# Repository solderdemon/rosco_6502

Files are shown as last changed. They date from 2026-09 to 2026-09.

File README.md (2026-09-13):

# Really Old-School Computer - 6502

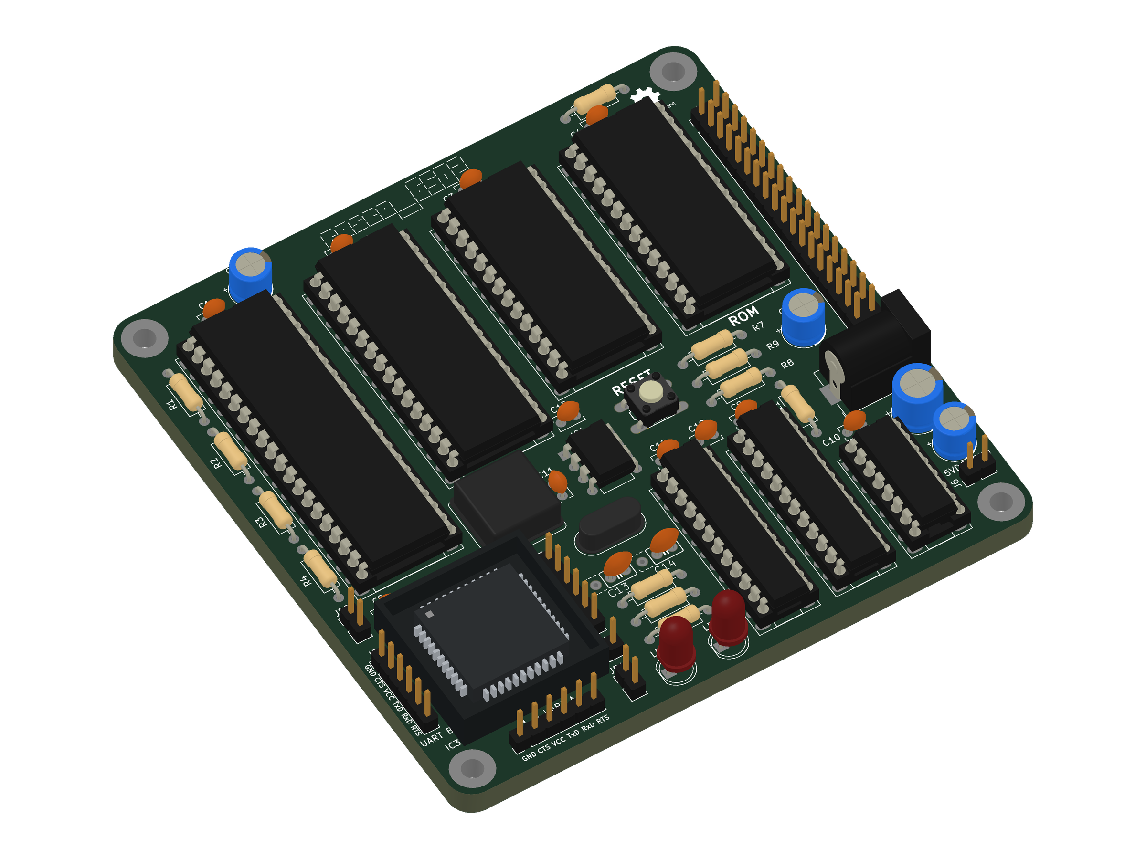
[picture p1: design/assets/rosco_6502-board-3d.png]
rosco_6502 r4 populated PCB in an orthographic 3D view


## A 65C02 Single-Board Computer

This repository holds design files, firmware and software for the Really Old-School Computer
(6502) single-board computer, AKA the rosco_6502. This is a fully-featured, programmable,
extensible and capable 8-bit retro computer that is completely open source.

The rosco_6502 is the "little brother" of the popular [rosco_m68k](https://github.com/rosco-m68k)
m68k computer. It is made by the same people, and shares the ethos of being powerful, extensible
and above all, fun.

This project contains all the design files and source code for the project.

* All Software released under the MIT licence. See LICENSE for details.
* All Hardware released under the CERN Open Hardware licence. See LICENCE.hardware.txt.
* All Documentation released under Creative Commons Attribution. See <https://creativecommons.org/licenses/by/2.0/uk/>

## Documentation

Start with the [documentation index](docs/README.md).

* [Getting started and terminal setup](docs/getting-started.md)
* [Hardware and memory map](docs/hardware.md)
* [Building and programming ROM](docs/rom-firmware.md)
* [Building and programming PLDs](docs/pld-firmware.md)
* [Developing and loading programs](docs/software.md)
* [Troubleshooting](docs/troubleshooting.md)
* [Revision 4 notes](docs/revision-4.md)

## Specifications

### Hardware

The hardware specifications for the rosco_6502 are:

* WDC 65C02 at up-to 14MHz (In theory, 10MHz testing target currently).
* SCN68681C1A44 provides two UARTs, timers and SD Card / SPI / GPIO; the console runs at 38400 bit/s
* 528KB RAM
  * 16KB low RAM ($0000 - $3FFF)
  * 16 x 32KB RAM banks ($4000 - $BFFF)
* 8KB IO space ($C000 - $DFFF)
* 8KB or 32KB (banked) ROM $E000 - $FFFF
* High-speed decode and glue logic handled by Atmel F22V10C PLDs.
* Comprehensive expansion and IO connectors allow the system to be easily expanded!

You can see the electrical designs in [kicad](design/kicad). Programmable logic lives in [pld](code/pld).

### Software

The current firmware uses the cc65 toolchain (`ca65`, `ld65` and `da65`).
It includes hardware initialization, WozMon, SD card access, read-only FAT32
support and boot code that looks for `/ROSC0DE_6502.BIN` on the SD card.
The firmware and filesystem utilities are still under development.

See the [firmware README](code/firmware/README.md) for build
instructions.

### Related tools

* [rosco CLI](https://github.com/solderdemon/rosco-cli): a cross-platform `rosco` command
  that creates, builds and uploads rosco_6502 (and rosco_m68k) programs over UART, or
  runs them in the emulator.
* [rosco-emulator](https://github.com/solderdemon/rosco-emulator): a slimmed-down MAME
  build that emulates the rosco_6502 r4, so programs and firmware can be tested without
  the board.

See [Developing and loading programs](docs/software.md#rosco-cli-and-emulator) for usage.

## Repository layout

* [design/kicad](design/kicad): board schematics and PCB layouts.
* [code/pld](code/pld): programmable logic sources.
* [code/firmware](code/firmware): ca65 firmware and ROM linker configurations.
* [code/software](code/software): example programs, tests and filesystem utilities.
* [docs](docs): additional project documentation.

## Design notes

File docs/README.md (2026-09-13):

# rosco_6502 Documentation

rosco_6502 is an open single-board computer built around the WDC 65C02, with banked memory, two UARTs and SD access over SPI. This guide covers the r4 board and the current ca65 firmware in this repository.

## Where to start

| Task | Guide |
| --- | --- |
| Power up the board and connect a terminal | [Getting started](getting-started.md) |
| Check power connections, ROM options and memory layout | [Hardware](hardware.md) |
| Build and program the EEPROM | [ROM firmware](rom-firmware.md) |
| Build JEDEC files and program IC2 and IC5 | [PLD firmware](pld-firmware.md) |
| Build a program and load it over UART or from SD | [Software development](software.md) |
| Build and run a program with the rosco CLI, with or without the board | [rosco CLI and emulator](software.md#rosco-cli-and-emulator) |
| Diagnose a failure | [Troubleshooting](troubleshooting.md) |
| Read the manufacturer's r4 notices | [Revision 4 notes](revision-4.md) |

For a new board, follow this sequence: inspect assembly and power connections → program both PLDs → program ROM → start with a terminal → load a RAM program.

## Repository layout

| Directory | Contents |
| --- | --- |
| [design/kicad](../design/kicad) | Schematic, PCB, symbol and footprint libraries, component CSV |
| [design/CAMOutputs](../design/CAMOutputs) | Gerber and drill files |
| [code/pld](../code/pld) | Logic equations, JEDEC files and programming scripts |
| [code/firmware](../code/firmware) | Main ca65 firmware |
| [code/software](../code/software) | Examples and filesystem utilities |

## Status and sources

The firmware is under development. FAT32 support is read-only; an API symbol does not necessarily identify an implemented function. Known limitations are documented in the ROM and troubleshooting guides.

Commands follow the Makefiles and scripts in this repository. Run `sh` blocks in Bash. On Windows, use an environment providing Bash, GNU Make and the required tools on PATH. Validate builds and physical programming in your own environment.

The former `r4 Information.docx` and `r4 Information.pdf` are replaced by [Revision 4 notes](revision-4.md), with technical details also included in the relevant guides. The schematic PDF in `design/kicad` remains a drawing.

## Licences

- Software: MIT, see [LICENSE](../LICENSE).
- Hardware: CERN Open Hardware Licence, see [LICENCE.hardware.txt](../LICENCE.hardware.txt).
- Documentation: [Creative Commons Attribution 2.0 UK](https://creativecommons.org/licenses/by/2.0/uk/), as stated in the project README.
- Original project authors: Ross Bamford and contributors. The r4 notice was issued by The Really Old-School Company Limited.

[Back to the project README](../README.md)

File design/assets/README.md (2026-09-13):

# Board preview assets

The main README uses `rosco_6502-board-3d.png`, an orthographic view rendered with OpenGL rasterization. It uses smooth surface normals, linear-light shading and soft rasterized highlights, with no ray tracing or shadow passes. The earlier bare-board top view is retained as `rosco_6502-board.png`.

## 3D models

The PCB references the KiCad 10 standard STEP library through `KICAD10_3DMODEL_DIR`. Install that library to resolve the models. DIP devices include socket models and IC bodies raised 3.5 mm above their normal mounting position. The 100 nF capacitors use compact 3.8 mm ceramic disc models with 2.5 mm lead pitch. C13/C14 retain their 5 mm ceramic disc models; S1 uses the Omron B3F-100x model.

The local [PLCC-44 model](../kicad/3dmodels/PLCC-44_socket_populated.wrl) illustrates the populated UART socket. Its geometry is approximate and is not a manufacturer model of the SCN68681C1A44 or a mechanical clearance specification. Its matching [box definitions](../kicad/3dmodels/PLCC-44_socket_populated.json) replace the converted PLCC geometry in the preview renderer to preserve its colours. The converted and local versions must not be drawn together, because overlapping surfaces cause artifacts. Local model coordinates are in millimetres in the JSON and converted to KiCad VRML units in the WRL.

The render preserves the board thickness and component placements in the PCB file. The preview uses charcoal sleeves for the stock blue electrolytic models. These are presentation colours; exact purchased part numbers were not specified. Generic models do not reproduce device markings or guarantee the dimensions and colours of the purchased components.

## Reproduce the image

Use KiCad 10 with its standard 3D library, Python, `numpy`, `trimesh`, `moderngl` and `Pillow`, and an OpenGL 3.3 capable graphics driver. Run from the repository root, with `kicad-cli` on PATH:

```sh
kicad-cli pcb export glb --output rosco-populated.glb --force --include-pads --include-silkscreen --include-soldermask design/kicad/rosco_6502.kicad_pcb
python design/assets/render_board.py rosco-populated.glb design/assets/rosco_6502-board-3d.png
```

The GLB is an intermediate file and does not need to be committed. The renderer adds the local UART visualization at the current IC3 position; update that placement in the script if IC3 is moved. It uses an orthographic camera and renders at twice the output resolution before downsampling to 1800 × 1400 pixels.

The local illustrative PLCC model is covered by the project's [hardware licence](../../LICENCE.hardware.txt). Standard KiCad models retain their upstream licences and are referenced rather than copied into this repository.

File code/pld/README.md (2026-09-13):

# rosco_6502 PLDs

[Building and programming PLDs](../../docs/pld-firmware.md) provides the full instructions for IC2 and IC5.

| Position | Source | JEDEC | Programming script |
| --- | --- | --- | --- |
| IC2 | [ic2_address_decoder.pld](address_decoder/ic2_address_decoder.pld) | [ic2_address_decoder.jed](address_decoder/ic2_address_decoder.jed) | [burn.sh](address_decoder/burn.sh) |
| IC5 | [ic5_glue_logic.pld](glue/ic5_glue_logic.pld) | [ic5_glue_logic.jed](glue/ic5_glue_logic.jed) | [burn.sh](glue/burn.sh) |

The scripts program existing JEDEC files into ATF22V10C(UES) devices. Run each script from its own directory. After changing equations, rebuild the JEDEC files as described in the guide before programming.

[Documentation index](../../docs/README.md)

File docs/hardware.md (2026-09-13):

# Hardware and memory map

[Documentation index](README.md)

## Main components

| Component | Purpose |
| --- | --- |
| WDC 65C02 | CPU |
| SCN68681C1A44 | Two UARTs, timer, GPIO for SPI and indicators |
| 16 KiB low RAM | Permanently mapped memory, stack and system structures |
| 16 × 32 KiB RAM | Banked memory; 528 KiB total including low RAM |
| AT28C64B or AT28C256 | 8 KiB ROM or four 8 KiB banks |
| IC2 | Address decoder PLD |
| IC5 | Glue logic PLD |

The original README specifies up to 14 MHz in theory, with 10 MHz as the testing target. This does not guarantee that every combination of components will operate at that frequency.

The current board uses an SCN68681C1A44 DUART, with the console configured for 38400 bit/s. Older design files and source comments may still refer to the previous XR68C681 device; check them against the populated board.

## CPU address space

| CPU addresses | Window size | Purpose |
| --- | --- | --- |
| `$0000–$3FFF` | 16 KiB | Low RAM; writes at the beginning also control banking |
| `$4000–$BFFF` | 32 KiB | Selected RAM bank, 0–15 |
| `$C000–$C00F` | 16 bytes | DUART registers |
| `$C010–$DFFF` | Remaining I/O | Reserved I/O space |
| `$E000–$FFFF` | 8 KiB | ROM; one of four banks with an AT28C256 |

`BANK_SET = $0000`: bits 0–3 select RAM and bits 4–5 select ROM. Preserve the ROM bits when changing the RAM bank. Do not switch banks while executing in the affected window without a deliberately arranged transition.

The headers reserve `$0001` as `BANK_RSVD`, but the IC2 equation decodes both `$0000/$0001`. Do not use either address as an ordinary variable. Reads return the contents of the underlying RAM.

## System RAM

| Range | Usage |
| --- | --- |
| `$0002–$000F` | Firmware zero page |
| `$0010–$001F` | Filesystem zero page according to the constants |
| `$0020–$002F` | Monitor zero page according to the constants |
| `$0030–$003F` | Avoid in portable examples: comments and constants disagree |
| `$0040–$00FF` | Application zero page in the example linker configurations |
| `$0100–$01FF` | CPU stack |
| `$0200–$023F` | Firmware variables and reserved space |
| `$0240–$029F` | RAM vector area |
| `$02A0–$02FF` | ROM switching helper code |
| `$0300–$03FF` | Input buffer |
| `$0400–$05FF` | Filesystem sector buffer |
| `$0600–$06FF` | Filename buffer |
| `$0700–$07FF` | Scratch buffer / bank copying |
| `$0800–$3FFF` | 14 KiB low RAM for applications |

The introductory table in `defines.inc` disagrees with the constants about zero page and the RAM vector boundaries. The vector boundaries above follow the linker configuration. The conservative application zero-page start follows the example configurations (`$0040`).

## Board design files

- [KiCad schematic](../design/kicad/rosco_6502.kicad_sch), [PDF schematic](../design/kicad/rosco_6502.pdf).
- [PCB](../design/kicad/rosco_6502.kicad_pcb), [KiCad project](../design/kicad/rosco_6502.kicad_pro).
- [Component CSV](../design/kicad/rosco_6502.csv), [manufacturing files](../design/CAMOutputs).
- [Firmware constants](../code/firmware/inc/defines.inc), [ROM linker configuration](../code/firmware/rosco_6502_32K.cfg).

Before manufacturing, check that the schematic, PCB and Gerber revisions match. The PLD source headers still say r1, whereas the hardware notice covers r4.

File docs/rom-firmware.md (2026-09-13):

# Building and programming ROM

[Documentation index](README.md)

The main firmware is in [code/firmware](../code/firmware). It initializes the DUART, timer and RAM vectors, checks memory banks and attempts to load a program from SD. If loading fails or the program returns with RTS, execution enters WozMon.

## Tools

You need `ca65`, `ld65` and `da65` from cc65, GNU Make, Bash, `cat` and `rm`. Programming also requires `minipro` and a programmer supporting the specific EEPROM. On Windows, run the commands in a Bash environment; USB programmer access must be configured separately.

Check tool availability in Bash:

```sh
command -v make bash ca65 ld65 da65 cat rm
command -v minipro
```

## Choose an image

| EEPROM | Image | Size | Programming target |
| --- | --- | --- | --- |
| AT28C64B | `boot8k.bin` | 8192 bytes | `make burn8` |
| AT28C256 | `boot32k.bin` | 32768 bytes | `make burn32` |

ROM appears at CPU address `$E000`, but the image is programmed from EEPROM offset 0. A RAM program intended for SD boot is not a ROM image.

## Build

From the repository root:

```sh
cd code/firmware
make clean
make all
wc -c boot8k.bin boot32k.bin
```

To build only one variant, run `make boot8k.bin` or `make boot32k.bin` after `make clean`.

Clean before rebuilding: the assembly rule references `S_INCLUDES`, but the Makefile does not define it. Editing an included `.s` or `.inc` file may therefore fail to trigger an object rebuild.

The 32 KiB image concatenates `boot32k.0.bin`, `boot32k.1.bin`, `boot32k.2.bin` and `boot32k.3.bin` in that order. Each bank is 8192 bytes. Program the combined `boot32k.bin` into an AT28C256.

Other outputs are `.lst` listings, `.sym` symbols, `.map` linker maps and `.dis` disassemblies. Existing files without the `.bin` extension do not replace the output of a clean build.

## Program the EEPROM

1. Disconnect board power, remove the EEPROM and check its markings.
2. Insert the EEPROM into the programmer using its placement guide and pin 1 orientation.
3. From the firmware directory, run only the target for the installed chip:

```sh
# AT28C64B, 8 KiB
make burn8
```

or:

```sh
# AT28C256, 32 KiB
make burn32
```

These Makefile targets execute the following commands respectively:

```sh
minipro -p AT28C64B -s -w boot8k.bin
minipro -p AT28C256 -s -w boot32k.bin
```

The commands are alternatives for different chips. Check the programmer's write and verification results before reinstalling the EEPROM. If your minipro version does not recognize the required chip, do not substitute another device profile.

4. Reinstall the EEPROM in the correct orientation with board power disconnected.
5. Follow [Getting started](getting-started.md). Startup code attempts to detect the ROM bank count. An incorrect result calls for checking the image and hardware bank selection.

## Source layout

| File | Responsibility |
| --- | --- |
| [bank0.s](../code/firmware/bank0.s) | Reset, initialization, checks and SD boot |
| [bank1.s](../code/firmware/bank1.s), [bank2.s](../code/firmware/bank2.s), [bank3.s](../code/firmware/bank3.s) | Other ROM banks |
| [common.s](../code/firmware/common.s), [vectors.s](../code/firmware/vectors.s) | Common code and CPU vectors |
| [romtable.s](../code/firmware/romtable.s), [ramtable.s](../code/firmware/ramtable.s) | Call tables and bank transitions |
| [duart_spi.s](../code/firmware/duart_spi.s), [sd_card.s](../code/firmware/sd_card.s) | SPI and SD |
| [fat32_readonly.s](../code/firmware/fat32_readonly.s) | FAT32 reading |
| [wozmon.s](../code/firmware/wozmon.s) | Monitor and Intel HEX loader |

The `rosco_6502_8K.cfg` and `rosco_6502_32K.cfg` linker configurations define the layout. CPU vectors start at `$FFFA`. Common regions must retain matching addresses across all banks.

## Limitations

The ROM table routes `FAT_READ`, `FAT_SEEK`, `FAT_WRITE` and `FAT_CLOSE` to a stub. Use implemented operations such as `FS_READBYTE` and `FS_READFILE` for reading. The current `CLRSCR`, `MOVEXY` and `SETCURSOR` RAM vectors jump to themselves; calling them directly can hang execution.

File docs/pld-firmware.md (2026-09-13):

# Building and programming PLDs

[Documentation index](README.md)

The PLDs implement hardware logic. Their JEDEC files are programmed separately from the EEPROM; building ROM does not update the PLDs.

## Device and file mapping

| Position | Function | Directory | Programming file |
| --- | --- | --- | --- |
| IC2 | Address decoder | [address_decoder](../code/pld/address_decoder) | `ic2_address_decoder.jed` |
| IC5 | Glue logic | [glue](../code/pld/glue) | `ic5_glue_logic.jed` |

Both `burn.sh` scripts use the `ATF22V10C(UES)` profile. The source files specify the `GAL22V10` architecture; this does not mean any GAL is a suitable replacement for the actual device. Check the chip markings and your board schematic.

## Files and tools

- `.pld`: source equations and pin assignments.
- `.jed`: JEDEC data for the programmer.
- `.pin`, `.chp`, `.fus`: pin, package and fuse-array reports.
- `burn.sh`: programs an existing JEDEC file without compiling it.

The checked-in JEDEC headers identify **GALasm 2.1**. Rebuilding requires GALasm. Programming requires Bash, minipro and a compatible programmer. See the [GALasm documentation](https://github.com/daveho/GALasm#readme) for syntax and options.

## Rebuild after changing the logic

From the repository root, build each PLD separately:

```sh
cd code/pld/address_decoder
galasm ic2_address_decoder.pld
```

```sh
cd code/pld/glue
galasm ic5_glue_logic.pld
```

The second block also starts from the repository root. The executable name depends on your installation: use `GALasm` instead of `galasm` if that is its name.

Compilation must finish without errors and generate the corresponding `.jed`. Review the pin reports and run `git diff -- code/pld` from the repository root to inspect changes. Do not program after a failed build: an older JEDEC file may still be present. This repository has no separate PLD Makefile.

If the equations have not changed, you can use the checked-in JEDEC files after confirming the board revision and device assignments.

## Program IC2

With board power disconnected, remove IC2 and insert it into the programmer according to its placement instructions. From the repository root:

```sh
cd code/pld/address_decoder
bash burn.sh
```

The script executes:

```sh
minipro -p 'ATF22V10C(UES)' -w ic2_address_decoder.jed
```

## Program IC5

Insert IC5 into the programmer separately. From the repository root:

```sh
cd code/pld/glue
bash burn.sh
```

The equivalent command is:

```sh
minipro -p 'ATF22V10C(UES)' -w ic5_glue_logic.jed
```

Quotes protect the parentheses in the device profile from Bash interpretation. The scripts use relative paths, so run each from its own directory.

After each operation, confirm that writing and verification completed successfully. Label the devices IC2 and IC5 to avoid mixing them up, then reinstall them in the correct orientation with board power disconnected.

## What the equations implement

IC2 selects low RAM, banked RAM, I/O, ROM, the DUART and the bank register. `BANKSEL` is active high; both `$0000` and `$0001` activate it.

IC5 generates `RD`, `WR`, `BANKCLK` and two ROM output-enable signals, and controls `RESET` and `RDY`. The source comment explains the two `BANKCLK` pulses during a write: an intermediate incorrect value is replaced by the correct value before banked RAM is used. This is an intentional timing tradeoff; changes require hardware measurements.

After installation, check ROM startup and the RAM banks. Successful JEDEC verification confirms device programming, but does not validate board timing. See [Troubleshooting](troubleshooting.md).

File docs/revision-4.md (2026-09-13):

# Revision 4 notes

[Documentation index](README.md)

This is a Markdown adaptation of **rosco_6502 Additional Information v1 (Jan 2024)** issued by The Really Old-School Company Limited. It replaces `r4 Information.docx` and `r4 Information.pdf`. The information applies to revision 4.

## JP1 and JP2

JP1 and JP2 are optional jumpers for powering the board through an FTDI module. Only one jumper may be closed at a time, and only when the board receives power from the corresponding module.

Do not close either jumper when external power is connected, and do not close both at once. Doing so may damage the board, FTDI modules, power supply and connected equipment.

The FTDI module and USB source must provide at least 400 mA for the main board alone. Insufficient power may cause incorrect operation and, in rare cases, permanent damage.

## Power connection

When not using FTDI power, supply 5 V DC through J6, the two-pin header at the bottom right of the board, or through J7, the barrel jack.

Higher voltage or incorrect polarity may permanently damage the board and peripherals. Follow the polarity markings on the board. J7 requires a centre-positive plug.

## ROM selection

The board supports an 8 KiB AT28C64B or a banked 32 KiB AT28C256. Program the standard firmware build matching the EEPROM capacity. The standard firmware detects and reports the ROM size at startup.

See the [ROM programming guide](rom-firmware.md) for commands.

## Manufacturer notices

The following preserves the substance of the manufacturer's January 2024 notices. It is not a new compliance assessment of an individually assembled board.

The manufacturer states that it has sought to make documentation accurate at the time of writing, subject to errors and omissions.

Compliance with local electromagnetic interference requirements may require a suitable grounded enclosure with application-specific shielding. The Really Old-School Company Limited neither specifies nor supplies such enclosures and recommends seeking expert guidance when selecting one.

The manufacturer does not authorize its products for safety-critical or life-support applications where a product failure could cause system failure or significantly affect system safety or effectiveness. Examples include human life support, nuclear safety and control, air-traffic control and vehicular control. Such use is not authorized under any circumstances.

According to the manufacturer, the PCBs and components it supplies comply with RoHS. Compliance of a completed kit also depends on the solder selected during assembly.

Dispose of waste in accordance with the applicable Waste Electrical and Electronic Equipment (WEEE) recycling requirements in your jurisdiction.

## Editorial notes

The original jumper warning referred to `rosco_m68k`; this adaptation uses “the board” to match the document's subject. Repeated section numbering has been replaced with headings. Power requirements and manufacturer notices have been preserved in substance.

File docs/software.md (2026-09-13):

# Developing and loading programs

[Documentation index](README.md)

RAM programs are built separately from ROM. The current ca65 examples link for execution at `$0800`, use the main firmware headers and can produce binary and Intel HEX files.

## Examples

| Directory | Purpose |
| --- | --- |
| [msg_test_ca65](../code/software/msg_test_ca65) | Simple message input and output |
| [fs_test_ca65](../code/software/fs_test_ca65) | Filesystem test |
| [fs_menushell](../code/software/fs_menushell) | Experimental filesystem utility |
| [msg_test](../code/software/msg_test), [sd_test](../code/software/sd_test), [fat_test](../code/software/fat_test) | Older VASM examples |

`fs_menushell` is not yet a complete command shell: its active path accepts input, passes it to `showdir` and exits.

## rosco CLI and emulator

Two companion projects cover the develop–upload–run loop outside this repository:

- [rosco CLI](https://github.com/solderdemon/rosco-cli) provides the `rosco` command for Linux and Windows. It creates a rosco_6502 project (a Makefile, sources and an ld65 configuration linked at `$0800`), builds it with cc65 either in Docker or on the host, uploads the binary as Intel HEX through the monitor, and shows the program's output.
- [rosco-emulator](https://github.com/solderdemon/rosco-emulator) is a MAME-based emulator with a `rosco_6502` machine: W65C02S, 16KB low RAM, 16 × 32KB RAM banks, banked ROM, XR68C681 DUART and SPI SD card. It can boot your own ROM image as well as run a program on the stock firmware.

A typical session with the CLI:

```sh
cargo install --path .          # in a rosco-cli checkout
rosco init hello --board rosco_6502 --language asm --target emulator
cd hello
rosco build
rosco run                       # in the emulator; use --hardware for the board
```

To run an existing binary directly in the emulator:

```sh
./rosco rosco_6502 -quik msg_test.bin
```

See each project's README for installation, the Docker images and all options. Validate results on the physical board as well, since the emulator does not reproduce every hardware timing detail.

## Build the test program

Use the same tools as for [ROM](rom-firmware.md), plus `srec_cat` to generate Intel HEX.

```sh
cd code/software/msg_test_ca65
make clean
make all
```

The outputs are `msg_test.bin` and `msg_test.hex`. If you only need the binary, run `make msg_test.bin`; this does not invoke `srec_cat`. Perform a clean build, especially after changing included files.

## Load through WozMon

1. Start the board without an SD boot file to enter the monitor.
2. Type `L` and press Enter.
3. Send `msg_test.hex` as text through the terminal. The loader expects Intel HEX, not XMODEM or a raw binary.
4. Wait for completion with no checksum errors.
5. Type `0800R` and press Enter.

If characters are lost during transfer, add a delay between lines in the terminal and retry. Do not run the program after a checksum error.

Useful monitor commands:

| Command | Action |
| --- | --- |
| `0800` | Inspect a byte |
| `0800.080F` | Inspect a range |
| `0800: A9 41 60` | Write bytes to RAM |
| `0800R` | Call the program at that address |
| `L` | Load Intel HEX |

## Boot from SD

The current FAT32 code searches the MBR for a partition of type `$0B` or `$0C` and checks for 512-byte sectors. Use an SDHC card with MBR partitioning and FAT32 for this boot path. exFAT, GPT and media without a partition table do not match this initialization path.

1. Back up any needed data before repartitioning or formatting the card.
2. Copy the RAM binary to the FAT32 root directory as **ROSC0DE_6502.BIN**. The character in `ROSC0DE` is the digit **0**.
3. For a test, copy and rename the built `msg_test.bin`. The boot filename exceeds 8.3 format, so preserve its full long filename.
4. Insert the card and restart the board.

The loader reads the file starting at `$0800` and executes `JSR $0800` after a successful read. The binary must not contain a load-address header. On reaching `$C000`, the reader continues at `$4000` in the next RAM bank. This does not give the application a linear address space beyond 64 KiB.

## Write your own program

Include `defines.inc` from the current firmware and use an example linker configuration. Start application zero page at `$0040`; leave system buffers and RAM vectors available to the firmware.

A minimal character output program, following normal ROM initialization:

```asm
.include "defines.inc"

.segment "CODE"
.global _start
_start:
    lda #'A'
    jsr PRINTCHAR
    rts
```

`PRINTCHAR` takes the character in A. `INPUTCHAR` waits for input and returns the character in A. For `FS_OPEN`, pass the string address with the low byte in A and the high byte in X. Check headers and implementations for other function contracts; do not assume registers are preserved.

Returning with RTS works if the program has maintained a valid stack. When using banking and the filesystem, follow the [memory map](hardware.md) and account for the [API limitations](rom-firmware.md).

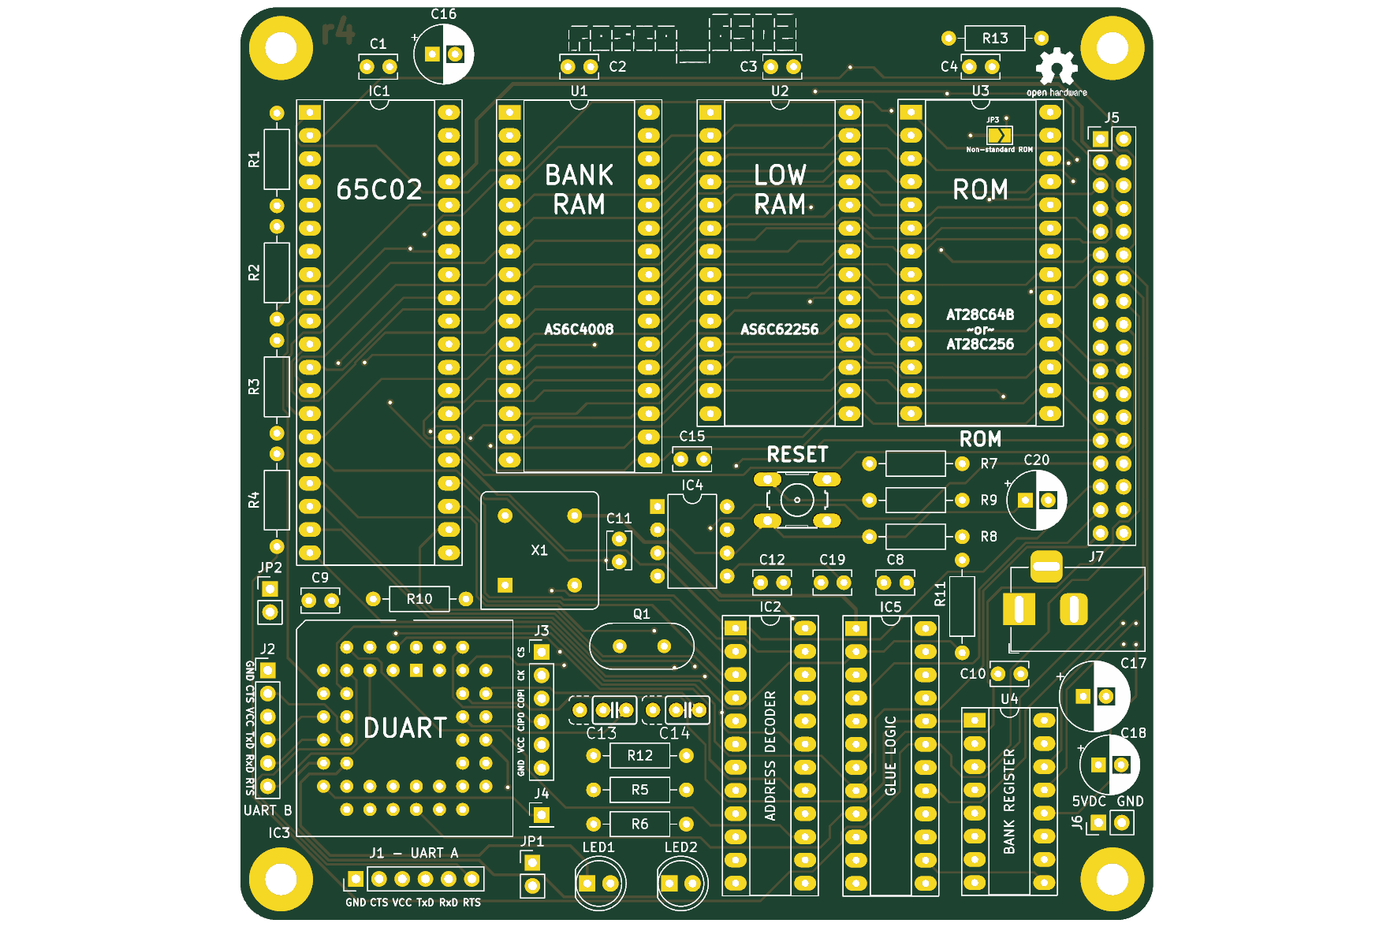
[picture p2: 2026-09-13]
design/assets/rosco_6502-board.png

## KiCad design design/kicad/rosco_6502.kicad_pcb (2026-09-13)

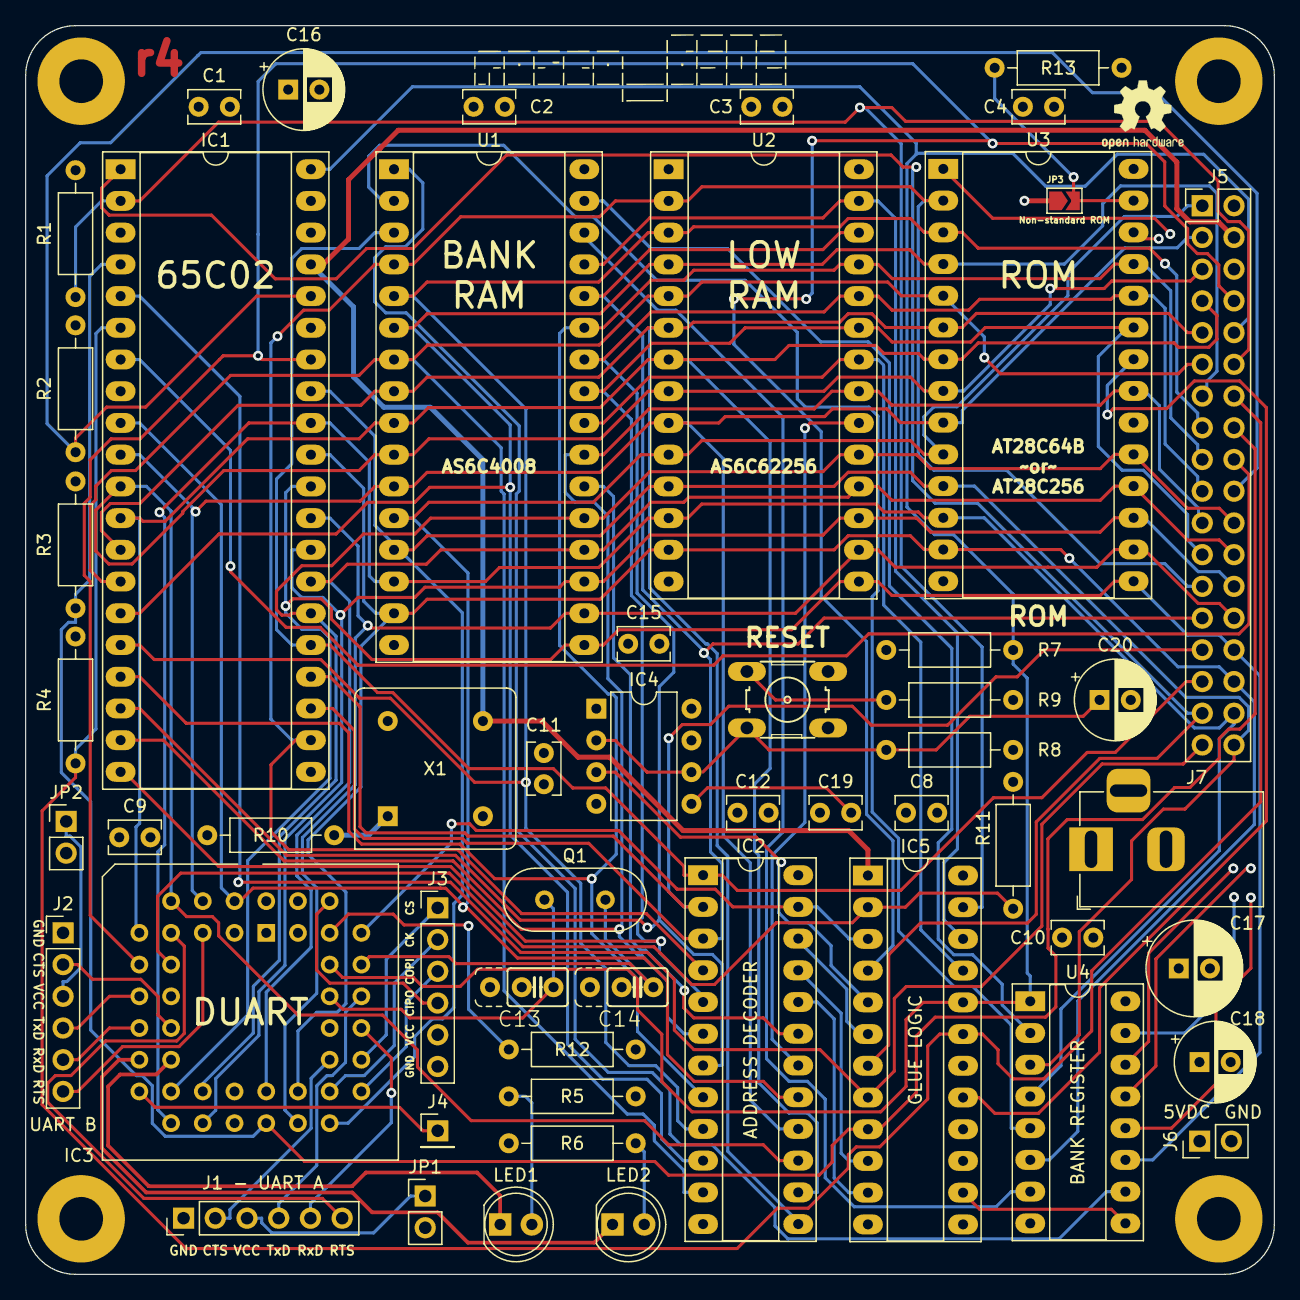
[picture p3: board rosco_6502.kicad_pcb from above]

Board: 4 copper layers, 100.0 x 100.0 mm, 60 parts (0 on the bottom side), 81 nets.

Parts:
C1, C2, C3, C4, C8, C9, C10, C11, C12, C15, C19: 100nF; C_Rect_L4.0mm_W2.5mm_P2.50mm
C13, C14: 7pF; C2.5_or_3.5-3
C16, C18: 100uF; CP_Radial_D6.3mm_P2.50mm
C17: 470uF; CP_Radial_D7.5mm_P2.50mm
C20: 10uF; CP_Radial_D6.3mm_P2.50mm
H1, H2, H3, H4: MountingHole_Pad; MountingHole_3.5mm_Pad
IC1: W65C02SxP; DIP-40_W15.24mm_Socket_LongPads
IC2, IC5: ATF22V10C-7PX; DIP-24_W7.62mm_Socket_LongPads
IC3: XR68C681CJTR-F; PLCC-44_THT-Socket
IC4: NE555P; DIP-8_W7.62mm
J1: UART_A; PinHeader_1x06_P2.54mm_Vertical
J2: UART_B; PinHeader_1x06_P2.54mm_Vertical
J3: Conn_01x06; PinHeader_1x06_P2.54mm_Vertical
J4: Conn_01x01_Male; PinHeader_1x01_P2.54mm_Vertical
J5: Conn_02x18_Odd_Even; PinHeader_2x18_P2.54mm_Vertical
J6: Conn_01x02_Pin; PinHeader_1x02_P2.54mm_Vertical
J7: Jack-DC; BarrelJack_Horizontal
JP1, JP2: Jumper; PinHeader_1x02_P2.54mm_Vertical
JP3: SolderJumper_2_Open; SolderJumper-2_P1.3mm_Open_TrianglePad1.0x1.5mm
LED1: GREEN; LED_D5.0mm
LED2: RED; LED_D5.0mm
Q1: 3.6864MHz; Crystal_HC49-4H_Vertical
R1, R2, R3, R4, R7, R10, R11, R12, R13: 3K3; R_Axial_DIN0207_L6.3mm_D2.5mm_P10.16mm_Horizontal
R5, R6, R9: 330R; R_Axial_DIN0207_L6.3mm_D2.5mm_P10.16mm_Horizontal
R8: 2K2; R_Axial_DIN0207_L6.3mm_D2.5mm_P10.16mm_Horizontal
S1: 10-XX; B3F-10XX
U1: AS6C4008-55PCN; DIP-32_W15.24mm_Socket_LongPads
U2: AS6C62256-55PCN; DIP-28_W15.24mm_Socket_LongPads
U3: AT28C256-15PU; DIP-28_W15.24mm_Socket_LongPads
U4: 74HCT174; DIP-16_W7.62mm_Socket_LongPads
X1: 14MHz; Oscillator_DIP-8
ohw: OSHW-Logo2_7.3x6mm_SilkScreen
rosco6502: rosco_6502

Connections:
A0: IC1.9 (A0), IC2.17 (I04), IC3.2 (A1), J5.1, U1.12 (A0), U2.10 (A0), U3.10 (A0)
A1: IC1.10 (A1), IC2.16 (IO3), IC3.4 (A2), J5.3, U1.11 (A1), U2.9 (A1), U3.9 (A1)
A2: IC1.11 (A2), IC2.15 (IO2), IC3.6 (A3), J5.5, U1.10 (A2), U2.8 (A2), U3.8 (A2)
A3: IC1.12 (A3), IC2.14 (IO1), IC3.7 (A4), J5.7, U1.9 (A3), U2.7 (A3), U3.7 (A3)
A4: IC1.13 (A4), IC2.13 (I13), J5.9, U1.8 (A4), U2.6 (A4), U3.6 (A4)
A5: IC1.14 (A5), IC2.11 (I11), J5.11, U1.7 (A5), U2.5 (A5), U3.5 (A5)
A6: IC1.15 (A6), IC2.10 (I10), J5.13, U1.6 (A6), U2.4 (A6), U3.4 (A6)
A7: IC1.16 (A7), IC2.9 (I9), J5.15, U1.5 (A7), U2.3 (A7), U3.3 (A7)
A8: IC1.17 (A8), IC2.8 (I8), J5.17, U1.27 (A8), U2.25 (A8), U3.25 (A8)
A9: IC1.18 (A9), IC2.7 (I7), J5.19, U1.26 (A9), U2.24 (A9), U3.24 (A9)
A10: IC1.19 (A10), IC2.6 (I6), J5.21, U1.23 (A10), U2.21 (A10), U3.21 (A10)
A11: IC1.20 (A11), IC2.5 (I5), J5.23, U1.25 (A11), U2.23 (A11), U3.23 (A11)
A12: IC1.22 (A12), IC2.4 (I4/PD), J5.25, U1.4 (A12), U2.2 (A12), U3.2 (A12)
A13: IC1.23 (A13), IC2.3 (I3), J5.27, U1.28 (A13), U2.26 (A13)
A14: IC1.24 (A14), IC2.2 (I2), J5.29
A15: IC1.25 (A15), IC2.1 (I1/CLK), J5.31, U1.3 (A14)
BANK0: U1.31 (A15), U4.2 (Q0)
BANK1: U1.2 (A16), U4.5 (Q1)
BANK2: U1.30 (A17), U4.7 (Q2)
BANK3: U1.1 (A18), U4.10 (Q3)
BANK4: U3.26 (A13), U4.15 (Q5)
BANK5: U3.1 (A14), U4.12 (Q4)
BANKCLK: IC5.14 (IO1), U4.9 (Cp)
BANKSEL: IC2.22 (IO9), IC5.6 (I6)
BE: IC1.36 (BE), J5.20, R2.2
CLK: IC1.37 (ϕ0), IC5.1 (I1/CLK), J5.4, X1.5 (OUT)
CTSA: IC3.8 (IP0), J1.6
CTSB: IC3.5 (IP1), J2.6
D0: IC1.33 (D0), IC3.28 (D0), J5.36, U1.13 (DQ0), U2.11 (DQ0), U3.11 (DQ0), U4.3 (D0)
D1: IC1.32 (D1), IC3.18 (D1), J5.34, U1.14 (DQ1), U2.12 (DQ1), U3.12 (DQ1), U4.4 (D1)
D2: IC1.31 (D2), IC3.27 (D2), J5.32, U1.15 (DQ2), U2.13 (DQ2), U3.13 (DQ2), U4.6 (D2)
D3: IC1.30 (D3), IC3.19 (D3), J5.30, U1.17 (DQ3), U2.15 (DQ3), U3.15 (DQ3), U4.11 (D3)
D4: IC1.29 (D4), IC3.26 (D4), J5.28, U1.18 (DQ4), U2.16 (DQ4), U3.16 (DQ4), U4.14 (D5)
D5: IC1.28 (D5), IC3.20 (D5), J5.26, U1.19 (DQ5), U2.17 (DQ5), U3.17 (DQ5), U4.13 (D4)
D6: IC1.27 (D6), IC3.25 (D6), J5.24, U1.20 (DQ6), U2.18 (DQ6), U3.18 (DQ6)
D7: IC1.26 (D7), IC3.21 (D7), J5.22, U1.21 (DQ7), U2.19 (DQ7), U3.19 (DQ7)
GND: C1.1, C2.1, C3.1, C4.1, C8.1, C9.1, C10.1, C11.1, C12.1, C13.1, C14.1, C15.1, C16.2, C17.2, C18.2, C20.2, H1.1, H2.1, H3.1, H4.1, IC1.21 (VSS), IC2.12 (GND), IC3.3 (IP3), IC3.22 (GND), IC4.1 (GND), IC5.12 (GND), J1.1, J2.1, J3.6, J5.6, J6.2, J7.2, JP3.1 (A), R9.2, U1.16 (VSS), U2.1 (A14), U2.14 (VSS), U3.14 (VSS), U3.20 (CE#), U4.8 (GND), X1.4 (GND)
HWRST: IC4.3 (Q), IC5.5 (I5)
IRQ: IC1.4 (~IRQ), IC3.24 (INTR), IC5.9 (I9), J5.16, R3.2
NMI: IC1.6 (~NMI), IC5.19 (IO6), J5.14, R4.2
unnamed: IC3.41 (*IACK), R12.2
unnamed: IC3.15 (OP3), LED2.1 (K)
unnamed: IC3.16 (OP5), LED1.1 (K)
unnamed: C13.2, IC3.36 (X1/CLK), Q1.1
unnamed: C14.2, IC3.37 (X2), Q1.2
unnamed: C19.2, IC4.5 (CV)
unnamed: C20.1, IC4.2 (TR), IC4.6 (THR), R8.1, S1.3
unnamed: JP3.2 (B), R13.1, U3.27 (WE#)
unnamed: LED1.2 (A), R5.1
unnamed: LED2.2 (A), R6.2
unnamed: R9.1, S1.1 (S)
unnamed: R10.2, X1.1 (EN)
RDY: IC1.2 (RDY), IC5.23 (IO10), J5.12, R1.2
RTSA: IC3.32 (OP0), J1.2
RTSB: IC3.14 (OP1), J2.2
RXDA: IC3.35 (RXDA), J1.4
RXDB: IC3.11 (RXDB), J2.4
R/~W: IC1.34 (R/~W), IC3.9 (*R/*W), IC5.4 (I4/PD), J5.8
SPICLK: IC3.30 (OP4), J3.2
SPICS: IC3.31 (OP2), J3.1
SPICS2: IC3.17 (OP7), J4.1
SPIMISO: IC3.40 (IP2), J3.4
SPIMOSI: IC3.29 (OP6), J3.3
SYNC: IC1.7 (SYNC), J5.18
TXDA: IC3.33 (TXDA), J1.5
TXDB: IC3.13 (TXDB), J2.5
VCC: C1.2, C2.2, C3.2, C4.2, C8.2, C9.2, C10.2, C11.2, C12.2, C15.2, C16.1, C17.1, C18.1, C19.1, IC1.8 (VDD), IC1.38 (~SO), IC2.24 (VCC), IC3.44 (VCC), IC4.4 (R), IC4.8 (VCC), IC5.24 (VCC), J3.5, J5.2, J6.1, J7.1, JP1.2 (B), JP2.2 (B), R1.1, R2.1, R3.1, R4.1, R5.2, R6.1, R7.1, R8.2, R10.1, R11.1, R12.1, R13.2, U1.32 (VCC), U2.28 (VCC), U3.28 (VCC), U4.16 (VCC), X1.8 (Vcc)
VCCUA: J1.3, JP1.1 (A)
VCCUB: J2.3, JP2.1 (A)
~BANKRAM: IC2.19 (IO6), U1.22 (CE#)
~DUADTACK: IC3.10 (*DTALK), IC5.2 (I2), R11.2
~DUASEL: IC2.23 (IO10), IC3.39 (CS), IC5.3 (I3)
~IO: IC2.20 (IO7), IC5.11 (I11)
~LOWRAM: IC2.18 (IO5), U2.20 (CE#)
~ML: IC1.5 (~ML), IC5.8 (I8), J5.35
~RD: IC5.21 (IO8), U1.24 (OE#), U2.22 (OE#)
~RESET: IC1.40 (~RES), IC3.38 (*RESET), IC5.20 (IO7), J5.10, R7.2, U4.1 (~Mr)
~ROMOE: IC5.17 (I04), U3.22 (OE#)
~ROM: IC2.21 (IO8), IC5.10 (I10)
~VP: IC1.1 (~VP), IC5.7 (I7), J5.33
~WR: IC5.22 (IO9), U1.29 (WE#), U2.27 (WE#)

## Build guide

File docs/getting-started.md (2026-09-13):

# Getting started

[Documentation index](README.md)

## What you need

Prepare an assembled board of the appropriate revision, programmed IC2 and IC5 devices, an EEPROM containing the matching ROM image, a 5 V DC supply and a UART adapter with logic levels compatible with the board schematic. Check connector pin assignments and orientation against the [schematic](../design/kicad/rosco_6502.pdf) and your board markings.

For an unprogrammed board, complete [PLD programming](pld-firmware.md), then [ROM programming](rom-firmware.md). Insert and remove ICs only with board power disconnected.

## Power

- Supply external 5 V DC through J6 or J7. J7 requires a centre-positive plug.
- Leave JP1 and JP2 open when using external power.
- When powering through FTDI, close only the JP1 or JP2 jumper corresponding to the connected module.
- Do not close both jumpers or combine FTDI power with an external supply.
- The r4 notice requires the FTDI power source to provide at least 400 mA for the main board alone. Peripherals need additional current.

See [Revision 4 notes](revision-4.md) for the complete notices.

## Terminal setup

The current board uses an SCN68681C1A44 DUART. The firmware's main console uses UART A. Connect adapter TX to board RX, adapter RX to board TX, and a common ground, checking the pins against the schematic. Connect the power line only as required by your chosen power arrangement.

| Setting | Value |
| --- | --- |
| Baud rate | 38400 bit/s |
| Data, parity, stop bits | 8N1 |
| Flow control | Disabled |
| Enter key | Send a single CR |
| Received CR display | CRLF |
| Emulation | VT100/ANSI for control sequences |

UART A and B are initialized in [bank0.s](../code/firmware/bank0.s). Its baud-rate comments still say `115k2` from the previous UART configuration; use the 38400 bit/s terminal setting above for the current SCN68681C1A44 board. The console RAM vector routes output to UART A.

## Check startup

1. Open the serial port in your terminal and power on the board.
2. Check the startup banner, memory information and RAM bank test result. This is a brief test of bank endpoints, not a complete memory test.
3. Without a usable SD card or boot file, the firmware should enter WozMon.
4. Enter `0800.080F` followed by Enter to inspect a range of RAM.
5. Load a [test program](software.md).

If the banner is missing or characters are corrupted, see [Troubleshooting](troubleshooting.md).

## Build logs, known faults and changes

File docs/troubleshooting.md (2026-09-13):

# Troubleshooting

[Documentation index](README.md)

## Build tools and programmer

| Symptom | Check |
| --- | --- |
| `ca65`, `ld65` or `da65` not found | cc65 must be on PATH in the current Bash environment |
| Make cannot find Bash, cat or rm | The Makefile requires Unix utilities; a plain PowerShell environment is insufficient |
| `srec_cat` not found | Required for `.hex`; an individual `.bin` target can be built without it |
| Output does not change after editing | Run `make clean`, then the desired target separately; include dependencies are incomplete |
| Warning about `S_INCLUDES` | This variable is undefined in the ROM Makefile; use a clean build |
| Link failure or ROM overflow | Inspect the `.map`, selected cfg and segment sizes |
| minipro cannot find the programmer | USB connection and access from the environment running minipro |
| minipro does not recognize the profile | Support for the exact device; do not substitute a similar name |
| PLD script cannot find JEDEC | Run from the directory containing the corresponding `burn.sh` |
| Write or verification failure | Orientation, contacts, profile and correct file for the device |

## Board and terminal

| Symptom | Check |
| --- | --- |
| No output | 5 V power, JP1/JP2, UART A, TX/RX/GND, ROM and IC2/IC5 placement |
| Garbled text | 38400, 8N1, flow control disabled and common ground |
| Unexpected Enter or line display behavior | Send one CR and display received CR as CRLF |
| Incorrect ROM detection | EEPROM model, complete image, four-bank order and bank selection lines |
| RAM bank test failure | IC2, IC5, bank register, RAM and solder joints on the relevant signals |
| Hang when calling screen APIs | `CLRSCR`, `MOVEXY` and `SETCURSOR` jump to themselves in the current RAM table |
| Intel HEX CRC errors | Add a line delay, use text transfer and reload |

## SD and FAT32

The boot code's `not found` message can arise at different stages: SD initialization, FAT32 initialization or file opening. Check them in order: card → MBR/FAT32 → full filename → valid binary for `$0800`.

`FS_ZP_ERRORCODE` values are defined in [defines.inc](../code/firmware/inc/defines.inc):

| Code | Meaning |
| --- | --- |
| 0 | No error |
| 1 | MBR signature check failed |
| 2 | FAT32 partition not found |
| 3 | Invalid BPB |
| 4 | Invalid RootEntCnt |
| 5 | Invalid TotalSec16 |
| 6 | Sector size is not 512 bytes |
| 7 | Media access error |
| 8 | Path too long |
| 9 | File or path not found |
| 10 | Read past end of file |
| 11 | Read extends beyond the last RAM bank |

The filesystem stores state in system RAM and zero page. If your program overwrites those areas, check its linker configuration. The existence of `BD_WRITE` does not imply support for writing FAT32 files.

## Reporting a problem

Include the board revision, ROM and PLD models, repository commit (`git rev-parse HEAD`), build command, complete error output and UART startup log. For programming failures, include the programmer model and selected profile. For failures after a code change, include the relevant diff and map file.

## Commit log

2026-09-13 docs: restructure documentation, add board renders and rosco CLI/emulator references
    [rosco_6502.kicad_pcb]
2026-09-13 firmware: remove legacy firstboot and move ca65 firmware to code/firmware
    [rosco_6502_32K.cfg, rosco_6502_8K.cfg]

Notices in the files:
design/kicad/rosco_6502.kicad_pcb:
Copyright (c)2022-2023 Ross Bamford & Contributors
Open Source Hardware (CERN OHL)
